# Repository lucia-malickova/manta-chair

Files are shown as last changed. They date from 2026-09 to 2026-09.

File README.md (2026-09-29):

# MANTA — the "one ribbon" chair (Open Chair)

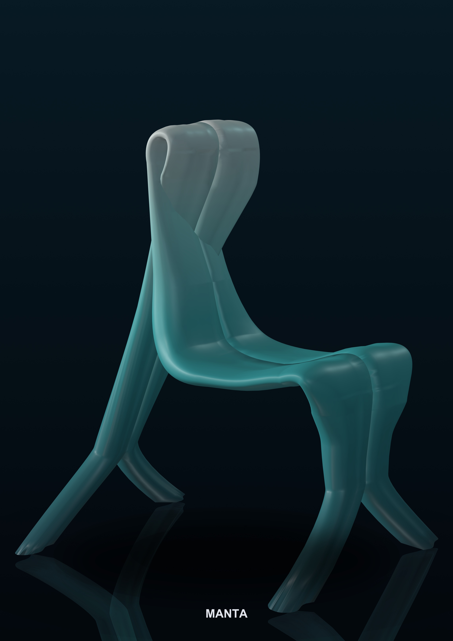
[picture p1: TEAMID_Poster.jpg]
MANTA poster


The whole chair is **one continuous ribbon**, **sliced crosswise** (like a
baguette) so every part fits a home printer and every joint stays strong.
Named for the manta ray — the forked feet read as fins, the tail-brace as a
fluke — and for the ocean's role as the planet's largest source of oxygen,
which the surface relief carries in its own graded texture, bold at the
floor and calming toward the crown.

No two of its 41 printed segments are identical, on purpose: nothing in
nature repeats, so nothing here does either. Change a few tables in
`manta_ribbon.py` and the same script regenerates a lighter, cheaper, or
differently-sized chair with the same joints — this repo *is* that script.

📄 [Full description (PDF)](TEAMID_Description.pdf) · 🖼 [Board](TEAMID_Board.jpg) · 🖼 [Poster](TEAMID_Poster.jpg)

Shared under **CC BY-NC-SA** — free to study, adapt, and reprint; not for
commercial resale.

---

## Requirements (Python packages)

```
pip install cadquery numpy scipy shapely trimesh matplotlib vtk pypdfium2 reportlab pillow
```

The first 3 are enough for the geometry itself. The rest are for the
renders / board / poster / PDF.

---

## Is everything OK? — one command

```
python manta_verify.py            # both variants, every check (~45 min)
python manta_verify.py --fast     # skips virtual assembly + PrusaSlicer (~5 min)
python manta_verify.py light      # one variant
```

It prints PASS/FAIL for strength, the print files (42 parts, all inside the
Prusa CORE One volume), peg clearance in the STLs, the virtual assembly, the
support PrusaSlicer really adds (< 2 %, < 0.5 g inside holes), and the
description/package limits — and ends with `ALL CHECKS PASSED` or the list
of what failed.

## Run order

| # | command | what it does | output |
|---|---|---|---|
| 1 | `python manta_ribbon.py` | **generator** — builds the ribbon, **slices it**, adds tenons + pins, exports the parts and the assembled chair | `MANTA_RIBBON/` |
| 1b | `python manta_print_ready.py manta_ribbon MANTA_RIBBON _print_ready_competition` | **print files**: generator -> least-support orientation that fits the bed (`manta_orient.py`, writes `ORIENT.json`) -> generator again, pin holes turned into teardrops pointing up for exactly those orientations -> same orientations applied | numbered, pre-rotated STLs |
| 1c | `python manta_slicer_check.py <folder>` | slices every part in **PrusaSlicer** (your own profile) and reports the support it really generates, and whether any of it is inside a hole | `SLICER_REPORT.txt` |
| 2 | `python manta_apply_template.py` | embeds the chair + numbered parts into the **official, unmodified** `3D_Template.stl` (chair centred in its 800x800mm footprint box, each part in its numbered 220x220x250mm cell) | overwrites `MANTA_RIBBON/MANTA_Chair.stl` + `MANTA_Assembly.stl` |
| 3 | `python manta_strength_check.py` | **strength + stability check** (first-order, pure math, live from the tables — also run automatically by step 1) | printed to the console |
| 4 | `python manta_ergonomics_check.py` | **ergonomics check** — 8 seat/backrest dimensions vs seating reference ranges | printed to the console |
| 5 | `python manta_uniqueness_check.py` | **uniqueness check** — proves no two segments share volume/area/bbox | printed to the console |
| 6 | `python manta_joint_test.py` | **physical joint test** — small pieces to print and glue | `MANTA_TEST/` |
| — | *renders and submission files:* | | |
| 7 | `python manta_render.py` | renders (poster + board views) | `_deliver/` |
| 8 | `python manta_explode.py` | exploded view + parts grid | `_deliver/` |
| 9 | `python manta_pdf.py` | description -> PDF | `TEAMID_Description.pdf` |
| 10 | `python manta_poster.py` | A2 poster | `TEAMID_Poster.jpg` |
| 11 | `python manta_board.py` | A2 board (on the official template) | `TEAMID_Board.jpg` |
| 12 | `python manta_package.py` | packs the submission files + checks total size | `ODOVZDANIE/` |

**Part numbering**: the official `3D_Template.stl` numbers its 49 cells
column-major (1,8,15,22,29,36,43 down column 1; 2,9,16,... down column 2;
etc) — that's fixed, unmodifiable template geometry. The Board's own key
graphic lays its numbers out row-major instead. Both are correct: only the
*number* has to match between the two (part "5" on the Board = part "5" in
the STL's cell "5"), not the box's on-page position.

**Slicing is NOT a separate file** — it lives inside `manta_ribbon.py`, in the
`build()` function: it makes crosswise cuts (by length + curvature, avoiding
the knee and lumbar), a lengthwise L/R cut on wide segments, conical tenons
at every cut, and a solid dia 11 pin only at the lumbar joints.

---

## Printing the parts

`TEAMID_Assembly.stl` is the **competition submission** format: all 42 parts
placed inside the official `3D_Template.stl` grid, because the brief
requires that. That template geometry is a non-solid reference grid (lines +
text, not a printable object) — a slicer will still try to load it alongside
your parts, which is confusing and pointless for an actual print.

For printing at home, use [`MANTA_RIBBON/`](MANTA_RIBBON) instead: the same
42 parts, no template geometry mixed in. Each file is named
`NN_SEG_xxx.stl`, where `NN` is the part number from the Board's key and the
exploded-view diagram (`01_SEG_00L.stl` = part 1, `42_PIN.stl` = part 42,
and so on) — so the file list itself tells you what to print against the
Board, no cross-referencing needed. `PARTS_LIST.txt` in that folder has the
same numbering.

**Every file in `MANTA_RIBBON/` and `MANTA_LIGHT/` is pre-rotated to the
orientation that needs the least support** — import and print as-is.

Honest numbers, **measured in PrusaSlicer** (`manta_slicer_check.py`
slices every file and reads the G-code back): a curved, fluted ribbon
segment can't always be printed with zero support, but it is **almost
support-free — under 1 % of the filament is support** (competition: 114 g
of 16.8 kg; `MANTA_LIGHT`: 83 g of 9.0 kg), all of it from the build plate,
most parts only a few grams. `manta_orient.py` tries ~400 orientations per
part and keeps the one that fits the Prusa CORE One's 250 x 220 x 270 mm
volume, stands on a solid base (>= 400 mm² footprint) and needs the least
support, with support inside a hole weighted 100x.

**Nothing grows inside the holes**, because each hole is shaped for the
way its part lies (`manta_teardrop.py`): a socket lying sideways gets a
teardrop roof pointing up, a socket end facing up is pointed (every
surface >= 60°), and the pin holes have no blind end at all — past the
pin's stop they narrow into a channel that runs out through the centre
seam. The one exception PrusaSlicer still shows is a ~0.3 g thin branch up
the pin channel of part 14; the channel is open at both ends, push it out
with a rod. `PARTS_LIST.txt` and `SLICER_REPORT.txt` in each folder list
the support per part.

In the slicer use **"Support on build plate only"** with an overhang
threshold of 45° or lower, never "Everywhere". (Earlier versions of these
docs claimed "no supports", then "29 of 42 parts need none"; neither was
checked in a real slicer, and the 45° socket points of that version still
got support inside them at a 45° threshold.)

---

## How to tune it

Everything is set in the `PARAMETERS` block at the top of `manta_ribbon.py`:
- `SPINE` — the ribbon's side profile (X = forward, Z = up)
- `W_S` — width along the length · `TH_S` — thickness along the length (follows the bending moment)
- `TWIST_S` — spiral twist of the section
- `SEG_MAX`, `FORK_SPLAY`, `TEN_R`, `PIN_R` ... — slicing and joints

`TEN_CLR = 0.12` mm was confirmed on a printed test joint (the cone slides
in with a little play; with the pin and no glue it already held hard).
Printers differ: print `MANTA_TEST/` (~2 h) first on yours, and if the
cone is too tight or too loose change `TEN_CLR` by 0.03 and regenerate.
The print STLs are exported at 0.03 mm tolerance so that this clearance
survives the export (`python manta_stl_fit_check.py` measures it).

**Every run of `manta_ribbon.py` re-checks itself.** Before exporting
anything, it calls `manta_strength_check.py`'s `worst_margin()`, which
re-derives the seat/lumbar/cut/leg section properties live from whatever
`W_S`/`TH_S` are currently set to (not a hand-copied snapshot) and runs the
same load case as the printed report. If tuning the tables has pushed the
weakest joint below the intended safety factor, generation stops with an
error instead of quietly writing an unsafe STL. Run
`python manta_strength_check.py` on its own any time for the full
13-check breakdown.

**A ready-made lighter variant — [`MANTA_LIGHT/`](MANTA_LIGHT).** Not
everyone needs a chair rated for a 120 kg dynamic sitter. `manta_ribbon_personal.py`
is the exact same generator with `TH_S` thinned to 75%, printed with 15%
gyroid and 4 perimeters; `manta_strength_check_personal.py` re-verifies it
for a **70 kg** sitter (x 1.8 dynamic x 2.0 safety): weakest glued check
**1.6x**, glued full-section joint **26x**. The PETG-only backup (peg + pin,
no epoxy) is **0.5x**, so this variant relies on the epoxy actually being
applied. With 15% infill the glue faces are only as good as their solid
skin: use at least 6 top / 5 bottom solid layers and only scuff them with
P120, don't sand through. Pins still at 100% infill. `MANTA_LIGHT/` is the
already-generated, numbered result: same 42 parts, same joints, about half
the filament (**9.0 kg vs 16.8 kg** in PrusaSlicer, ~160 h vs ~470 h; `manta_material_personal.py` for the
cost at your own filament price). Load-test it before sitting on it
(30 -> 50 -> 70 kg, each overnight). A demonstration variant, not the
competition entry — the competition files are untouched.

Want to print it in more than one colour? `python manta_colour_guide.py`
buckets the 41 segments into 4 filament colours by height (floor -> crown),
matching the same gradient the renders already use — prints exactly which
part numbers go in which colour and how many kg/EUR of each. Multi-colour
costs nothing extra: it's the same total filament, just split across spools.

---

## How the joint holds (so you don't have to worry)

The joint is **not "just a pin."** In order of importance:

1. **The full solid cross-section, glued face-to-face.** Every cut is
   perpendicular to the ribbon's axis, so you're gluing two flat faces of
   solid material against each other — 6,600–17,000 mm² of epoxy per joint.
   This is the main strength. (Margin in the strength check: **~26x**; the
   epoxy on the peg **3.5x**, counting only 80 % of its side because a
   sideways socket has a teardrop roof; weakest glued check **2.1x** — see
   `manta_strength_check.py`.)
2. **A conical peg (dia 27 at the face, 22 mm long)** at the centre of the
   cut — self-centring, it aligns the joint and carries shear. Only 3 mm of
   it is fused into its own part; the rest sits in the neighbour's socket
   (0.6 mm deeper than the peg, so the glue faces meet, not the tip; the
   socket's pointed end stays empty and takes the surplus glue and air).
3. **Dia 11 x 133 mm pins, printed SOLID (100% infill) and lying on
   their 2.2 mm flat** (so the layers run along the pin) — ONLY at the 2
   joints beside the lumbar, two per joint. One straight line per joint runs
   through both halves' pegs; from each side face a hole runs in along it,
   narrows in a long taper (the pin's stop) and continues as a dia 7 channel
   out through the centre seam — no blind end, so nothing inside it needs
   support. Slide each pin in until it stops. No pin sticks out; in three
   holes it ends 1 mm below the surface, in one ~27 mm below (the peg there
   sits deeper) — fill that mouth with epoxy. A cone in a cone slides straight out, so without glue
   the pin is the only thing holding it: the backup is peg root -> peg ->
   pin in *series*, and its capacity is the weakest of those. With the pin
   placed close to the face it comes to **0.9x** of the full design load
   (governed by the peg tearing out behind the pin) — a real limp-home
   backup, not a second main joint. An earlier version of the check *added*
   the peg and pin strengths together and reported 1.6x; that was wrong.

`python manta_joint_check.py` rebuilds every part and virtually assembles
the chair: every peg must land in its neighbour's socket, no peg end may
stick out of its own part, every socket must be closed inside ONE part
with at least 2 mm of wall around it, pins may only sit in holes, and no
two neighbouring parts may overlap. Where a whole piece meets a split L/R
pair (and vice versa) the whole piece carries two pegs, one per half, so no
socket is split across the seam. Every joint gets a peg in both variants;
where the part is thin the generator shortens the peg rather than leave less
than 2 mm of wall (it lists those in its report).

**Assembly order matters:** glue each L+R pair of a segment together
FIRST (their seam peg runs sideways, along that segment's own twisted
width direction), and only then join the segments crosswise (all crosswise
pegs of a joint are parallel, so a finished segment slides straight on).
The other way round cannot be assembled. Each part's number is engraved on
one of its glue faces (hidden once glued).

Epoxy on PETG: **sand the face (P120) and degrease** before gluing — otherwise
the epoxy won't bond well. Leave it clamped to cure for 24 h.

---

## Code files

- `manta_ribbon.py` — generator + slicing + joints + export
- `manta_apply_template.py` — embeds the chair/parts into the official `3D_Template.stl`
- `manta_strength_check.py` — strength + stability
- `manta_ergonomics_check.py` — seat/backrest dimensions vs standard reference ranges
- `manta_stl_fit_check.py` — measures the peg/socket clearance left in the exported print STLs
- `manta_joint_check.py` — virtual assembly: every peg seats in its neighbour, nothing sticks out or overlaps
- `manta_uniqueness_check.py` — proves no two of the 41 segments are geometrically identical
- `manta_orient.py` — rotates each part to the orientation needing the least support that fits the bed (solid base kept); writes `ORIENT.json`
- `manta_teardrop.py` — shapes sockets and pin holes for that orientation (teardrop roofs, pointed ends, pin channels) so nothing inside them needs support
- `manta_print_ready.py` — runs generator -> orient -> generator -> orient in the right order for one variant
- `manta_slicer_check.py` — slices every part in PrusaSlicer and reports the support it really adds (and any inside a hole), filament and print time
- `manta_print_list.py` — writes the numbered `PARTS_LIST.txt` with the slicer's per-part support
- `manta_joint_test.py` — physical joint test
- `manta_material.py` — filament use + cost from the real STL parts
- the remaining `manta_*.py` files = rendering / submission packaging
- `MANTA_Description_DRAFT.md` — the description text (edit, then run `manta_pdf.py`)
- `_board_base.png` — the rasterised official board template (without instructions)
- `3D_Template.stl` — the official 3D print file template (unmodified, as provided)
- `MANTA_RIBBON/` — the 42 individual part STLs, clean and ready to print (no template geometry) — see "Printing the parts" above

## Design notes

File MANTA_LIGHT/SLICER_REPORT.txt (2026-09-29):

# PrusaSlicer, profile: 0.28mm DRAFT @COREONE HF0.4 - Copy / Prusa CORE One HF0.4 nozzle / Prusament PETG @COREONE HF0.4 + top_solid_layers = 6
# part	support moves	of them inside a hole	support grams	part grams	support grams in holes	hours
01_SEG_00L.stl	37476	0	6.4	201	0.00	4.64
02_SEG_00R.stl	19457	0	4.3	195	0.00	3.96
03_SEG_01L.stl	11597	17	1.8	147	0.00	2.88
04_SEG_01R.stl	13867	0	2.4	152	0.00	3.13
05_SEG_02L.stl	1915	0	0.3	250	0.00	3.91
06_SEG_02R.stl	28396	17	4.9	276	0.00	5.38
07_SEG_03L.stl	67173	0	9.0	392	0.00	8.97
08_SEG_03R.stl	79090	0	10.7	447	0.00	10.23
09_SEG_04L.stl	1786	0	0.3	344	0.00	5.23
10_SEG_04R.stl	0	0	0.0	351	0.00	5.19
11_SEG_05L.stl	3401	0	0.6	350	0.00	5.50
12_SEG_05R.stl	13030	111	2.7	362	0.02	5.99
13_SEG_06L.stl	46219	0	7.1	488	0.00	8.86
14_SEG_06R.stl	15668	1044	4.4	468	0.30	7.83
15_SEG_07L.stl	1829	0	0.3	368	0.00	5.56
16_SEG_07R.stl	0	0	0.0	370	0.00	5.53
17_SEG_08L.stl	1809	0	0.3	198	0.00	3.09
18_SEG_08R.stl	23551	41	3.6	225	0.01	4.28
19_SEG_09L.stl	4226	0	0.7	163	0.00	2.84
20_SEG_09R.stl	2087	0	0.3	176	0.00	2.85
21_SEG_10L.stl	5947	0	0.8	154	0.00	2.59
22_SEG_10R.stl	6893	0	1.7	173	0.00	2.86
23_SEG_11L.stl	22135	0	3.6	125	0.00	2.97
24_SEG_11R.stl	5008	0	1.6	141	0.00	2.33
25_SEG_12L.stl	4236	0	0.5	129	0.00	2.21
26_SEG_12R.stl	4670	0	1.1	147	0.00	2.42
27_SEG_13L.stl	1301	0	0.2	96	0.00	1.59
28_SEG_13R.stl	3455	0	0.8	104	0.00	1.80
29_SEG_14.stl	0	0	0.0	160	0.00	2.54
30_SEG_15.stl	0	0	0.0	167	0.00	2.59
31_SEG_16.stl	0	0	0.0	172	0.00	2.69
32_SEG_17.stl	0	0	0.0	182	0.00	2.84
33_SEG_18.stl	0	0	0.0	200	0.00	3.06
34_SEG_19L.stl	964	0	0.2	120	0.00	2.05
35_SEG_19R.stl	853	0	0.2	120	0.00	2.02
36_SEG_20L.stl	6661	0	0.7	102	0.00	2.15
37_SEG_20R.stl	5599	0	0.6	98	0.00	1.94
38_SEG_21L.stl	15134	0	2.1	119	0.00	2.83
39_SEG_21R.stl	14121	0	2.2	121	0.00	2.71
40_SEG_22L.stl	20738	0	2.9	134	0.00	3.19
41_SEG_22R.stl	24152	0	3.8	142	0.00	3.38
42_PIN.stl	126	0	0.0	10	0.00	0.17

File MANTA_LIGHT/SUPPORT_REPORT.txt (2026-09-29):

01_SEG_00L.stl	73.2	93
02_SEG_00R.stl	52.1	988
03_SEG_01L.stl	27.1	1593
04_SEG_01R.stl	36.1	3996
05_SEG_02L.stl	2.5	3436
06_SEG_02R.stl	59.2	696
07_SEG_03L.stl	102.1	6693
08_SEG_03R.stl	116.5	6506
09_SEG_04L.stl	2.4	6485
10_SEG_04R.stl	0.0	6208
11_SEG_05L.stl	3.2	6023
12_SEG_05R.stl	19.4	444
13_SEG_06L.stl	97.4	9946
14_SEG_06R.stl	42.1	494
15_SEG_07L.stl	2.5	10489
16_SEG_07R.stl	0.0	10305
17_SEG_08L.stl	2.5	6993
18_SEG_08R.stl	40.7	847
19_SEG_09L.stl	3.6	4570
20_SEG_09R.stl	2.1	4403
21_SEG_10L.stl	8.8	4013
22_SEG_10R.stl	9.8	420
23_SEG_11L.stl	46.9	845
24_SEG_11R.stl	7.5	503
25_SEG_12L.stl	7.2	3225
26_SEG_12R.stl	6.6	413
27_SEG_13L.stl	1.2	2480
28_SEG_13R.stl	4.8	448
29_SEG_14.stl	0.0	4384
30_SEG_15.stl	0.0	4706
31_SEG_16.stl	0.0	5039
32_SEG_17.stl	0.0	5342
33_SEG_18.stl	0.0	5815
34_SEG_19L.stl	0.4	3047
35_SEG_19R.stl	0.3	2946
36_SEG_20L.stl	18.2	3438
37_SEG_20R.stl	12.1	3324
38_SEG_21L.stl	38.1	4052
39_SEG_21R.stl	34.8	3917
40_SEG_22L.stl	50.9	4784
41_SEG_22R.stl	54.5	5445
42_PIN.stl	0.0	1338

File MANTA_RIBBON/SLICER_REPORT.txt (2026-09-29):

# PrusaSlicer, profile: 0.28mm DRAFT @COREONE HF0.4 - Copy / Prusa CORE One HF0.4 nozzle / Prusament PETG @COREONE HF0.4 + layer_height = 0.2;perimeters = 5;fill_density = 35%
# part	support moves	of them inside a hole	support grams	part grams	support grams in holes	hours
01_SEG_00L.stl	49347	0	8.3	306	0.00	9.71
02_SEG_00R.stl	24131	0	5.2	314	0.00	9.19
03_SEG_01L.stl	22411	6	3.2	258	0.00	7.70
04_SEG_01R.stl	23312	0	3.3	262	0.00	7.76
05_SEG_02L.stl	2546	0	0.4	502	0.00	13.35
06_SEG_02R.stl	63446	41	11.9	512	0.01	15.99
07_SEG_03L.stl	135787	0	19.7	783	0.00	26.32
08_SEG_03R.stl	86796	0	10.2	820	0.00	25.63
09_SEG_04L.stl	2581	0	0.3	695	0.00	18.32
10_SEG_04R.stl	0	0	0.0	710	0.00	18.62
11_SEG_05L.stl	5005	0	0.8	711	0.00	19.35
12_SEG_05R.stl	0	0	0.0	717	0.00	18.83
13_SEG_06L.stl	66952	0	9.4	976	0.00	28.02
14_SEG_06R.stl	32755	1089	7.3	978	0.24	27.54
15_SEG_07L.stl	2432	0	0.3	748	0.00	19.88
16_SEG_07R.stl	0	0	0.0	761	0.00	20.24
17_SEG_08L.stl	2212	0	0.3	395	0.00	10.46
18_SEG_08R.stl	0	0	0.0	398	0.00	10.53
19_SEG_09L.stl	5614	0	0.8	301	0.00	8.12
20_SEG_09R.stl	2775	0	0.4	325	0.00	8.50
21_SEG_10L.stl	10134	0	1.2	276	0.00	7.38
22_SEG_10R.stl	29752	80	3.8	321	0.01	9.56
23_SEG_11L.stl	35549	21	4.0	197	0.00	6.45
24_SEG_11R.stl	7286	0	1.8	249	0.00	6.48
25_SEG_12L.stl	11885	0	1.2	212	0.00	5.79
26_SEG_12R.stl	7047	0	1.4	237	0.00	6.07
27_SEG_13L.stl	2123	0	0.2	166	0.00	4.46
28_SEG_13R.stl	5712	0	1.2	172	0.00	4.44
29_SEG_14.stl	0	0	0.0	287	0.00	7.41
30_SEG_15.stl	0	0	0.0	320	0.00	8.32
31_SEG_16.stl	0	0	0.0	334	0.00	8.78
32_SEG_17.stl	0	0	0.0	358	0.00	9.51
33_SEG_18.stl	0	0	0.0	395	0.00	10.49
34_SEG_19L.stl	1301	0	0.3	227	0.00	6.10
35_SEG_19R.stl	1189	0	0.3	231	0.00	6.24
36_SEG_20L.stl	3115	34	0.6	171	0.01	4.71
37_SEG_20R.stl	10795	0	1.1	170	0.00	4.94
38_SEG_21L.stl	25738	0	3.1	189	0.00	5.89
39_SEG_21R.stl	24309	0	3.2	197	0.00	6.11
40_SEG_22L.stl	32624	0	4.0	198	0.00	6.44
41_SEG_22R.stl	28536	17	4.4	214	0.00	6.66
42_PIN.stl	0	0	0.0	11	0.00	0.23

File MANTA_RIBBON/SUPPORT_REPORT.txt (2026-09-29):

01_SEG_00L.stl	82.2	763
02_SEG_00R.stl	44.7	1298
03_SEG_01L.stl	36.6	518
04_SEG_01R.stl	47.6	4687
05_SEG_02L.stl	2.5	4401
06_SEG_02R.stl	78.4	2125
07_SEG_03L.stl	215.2	484
08_SEG_03R.stl	104.6	8410
09_SEG_04L.stl	2.6	8618
10_SEG_04R.stl	0.0	8278
11_SEG_05L.stl	3.7	8219
12_SEG_05R.stl	0.0	7877
13_SEG_06L.stl	100.2	13224
14_SEG_06R.stl	67.4	765
15_SEG_07L.stl	2.5	13360
16_SEG_07R.stl	0.0	13180
17_SEG_08L.stl	2.5	8832
18_SEG_08R.stl	0.0	8692
19_SEG_09L.stl	3.6	5920
20_SEG_09R.stl	2.1	5747
21_SEG_10L.stl	9.5	5223
22_SEG_10R.stl	44.1	711
23_SEG_11L.stl	43.6	4896
24_SEG_11R.stl	10.0	591
25_SEG_12L.stl	14.1	4149
26_SEG_12R.stl	8.9	499
27_SEG_13L.stl	2.1	3143
28_SEG_13R.stl	9.5	504
29_SEG_14.stl	0.0	5382
30_SEG_15.stl	0.0	5875
31_SEG_16.stl	0.0	6348
32_SEG_17.stl	0.1	6749
33_SEG_18.stl	0.0	7369
34_SEG_19L.stl	0.7	3924
35_SEG_19R.stl	0.4	3798
36_SEG_20L.stl	3.3	457
37_SEG_20R.stl	17.2	4251
38_SEG_21L.stl	45.9	4913
39_SEG_21R.stl	41.2	4753
40_SEG_22L.stl	56.9	5443
41_SEG_22R.stl	48.9	1183
42_PIN.stl	0.0	1338

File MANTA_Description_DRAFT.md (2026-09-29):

# MANTA

**One continuous ribbon. One gesture. Cut like a baguette so it can be printed at home and still hold an adult.**

## Idea

MANTA is a single thick ribbon: floor, dished seat, cantilevered backrest,
forward-curled crown, tail-brace, back to the floor — no separate legs, no
frame, no visible assembly. The name is literal: forked feet read as fins,
the tail-brace as a fluke. The ocean makes most of the oxygen we breathe,
and the manta ray is one of its health indicators — so the surface carries
the story too: flutes that follow the ribbon's own motion, bold at the
floor and easing toward the crown, capped where you sit so they never press into a bone.

## Biomimicry as structure, not ornament

Each rule carries load:

- **Wolff's law** — thickness follows the bending moment: 84 mm at the lumbar
  knot, 50 mm at the knee, a 32 mm blade at the crown.
- **Murray's law** — the lumbar, the one true junction, is the cube-root-sum
  of seat, backrest and tail; every transition filleted.
- **Spiral fibre** — the flutes follow the stress path and stiffen by
  corrugation; the section twists up to 20° through the backrest.
- **Shell curvature** — the closed superelliptical section and dished seat
  carry load in membrane action.
- **Fiddlehead scroll** — the forward-curled crown closes the backrest into a
  tube, not an open cantilever.
- **Buttress roots** — each foot forks into two splayed prongs.

## Printing

41 segments (each ≤ 212 × 220 × 250 mm), auto-oriented for the least
support: **almost support-free**, under 1 % of the filament (PrusaSlicer),
none inside the holes — each is shaped for the way its part lies. PETG,
0.2 mm layers, 5 perimeters, 35 % gyroid, solid pins. ~17 kg, ~470 h on
one printer, ~90 €.

## Assembly — computed joints, no screws

Cuts and joints are computed, not drawn by hand. The script slices the
ribbon **crosswise** by length and curvature, keeping every cut ≥ 70 mm from
the knee and lumbar, where bending peaks. Every joint is a full solid cross-section (7,000–17,000 mm²),
epoxied, with a self-centring conical peg sized to the local thickness,
centred on its face, shrunk until its socket keeps a 2 mm wall.
Wide segments split along a flute-hidden keel. Only the two most-loaded
lumbar joints add a solid Ø11 pin. Every part's number is engraved on a glue face.
One command (manta_verify.py) re-checks it all: strength, a **virtual
assembly** (pegs seated, 2 mm walls, no overlaps), bed fit, real-slicer support.

## Stability and load

First-order check (120 kg × 1.8 dynamic × 2.0 safety): every member passes; glued full-section joint 26×,
weakest glued check 2.1×; with no glue at all, peg and pin still carry
0.9×. Tipping 0.56 sideways, 0.55–0.77 rearward; safe static load
~250 kg. Seat 429 × 364 mm, 428 mm high; 8/8 ergonomics checks pass.

## Open design — nothing repeats

Nothing in nature repeats, so no two parts here do either: all 41
segments are geometrically unique (script-verified). Change
the tables and the script regenerates a leaner chair with its joints and
checks; a 70 kg, half-filament variant is in the repo (link below).

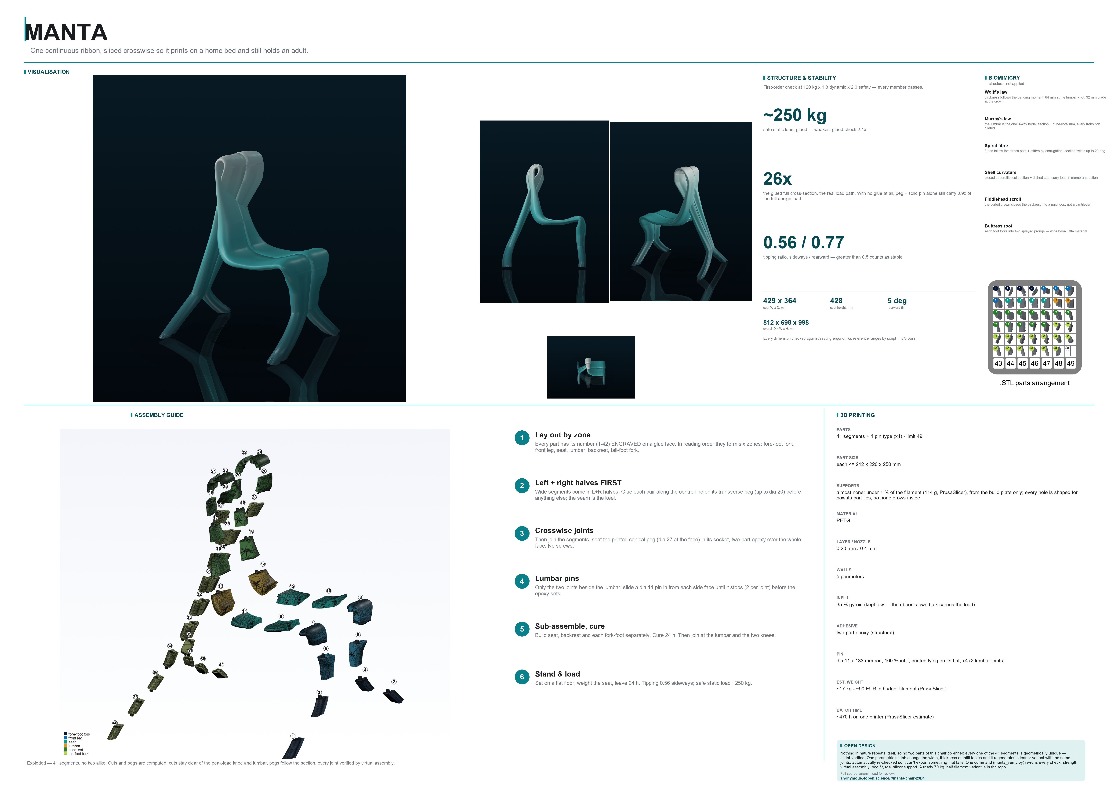
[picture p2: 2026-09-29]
TEAMID_Board.jpg

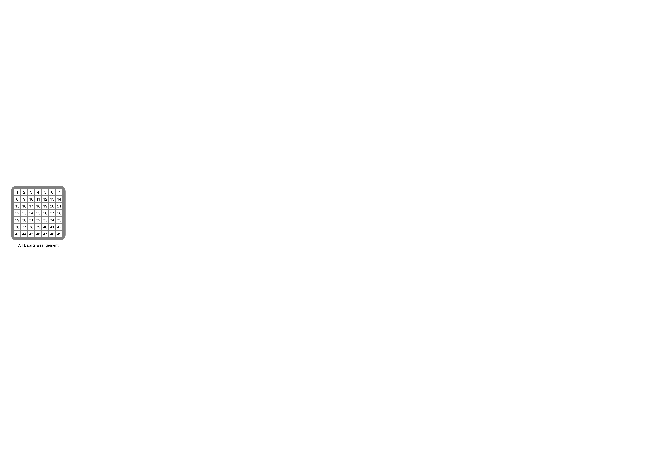
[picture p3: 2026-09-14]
_board_base.png

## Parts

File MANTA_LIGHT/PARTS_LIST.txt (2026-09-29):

MANTA — numbered, pre-oriented printable parts (matches Board key)

LIGHT variant — 70 kg design occupant, NOT the competition entry.
Print settings it was checked for (manta_strength_check_personal.py):
  4 perimeters, 15 % gyroid infill, >= 6 top / 5 bottom solid layers;
  PIN: 100 % infill (solid). Load-test before use: 30 -> 50 -> 70 kg.

Each file is pre-rotated to the orientation needing the LEAST support, on a solid
base (python manta_orient.py) — import and print as-is. Slicer: "Support on build
plate only" (never "Everywhere"), overhang threshold 45° or lower. Every hole is
shaped for the way its part lies: sockets that lie sideways have a teardrop roof,
ends that face up are pointed, pin holes run on through the seam as a narrow
channel -- so no support grows inside them (checked in PrusaSlicer).
Pins: 100 % infill, lying on their flat.
Every peg sits in a socket closed inside ONE neighbour part with >= 2 mm wall
(python manta_joint_check.py); >= 0.06 mm clearance survives in these STL files
(python manta_stl_fit_check.py). Each part number is ENGRAVED on a glue face.
ASSEMBLY: glue each L+R pair first, then join segments. Print both halves of a
segment from the SAME version of the files.

Support tags below = what PrusaSlicer, profile: 0.28mm DRAFT @COREONE HF0.4 - Copy / Prusa CORE One HF0.4 nozzle / Prusament PETG @COREONE HF0.4 + top_solid_layers = 6 actually generates.

BOARD LEGEND  (42 items, limit 49)
 1. SEG_00L      1x   SUPPORT from build plate (~6 g)
 2. SEG_00R      1x   SUPPORT from build plate (~4 g)
 3. SEG_01L      1x   SUPPORT from build plate (~2 g)
 4. SEG_01R      1x   SUPPORT from build plate (~2 g)
 5. SEG_02L      1x   a few specks of support from the build plate (< 1 g)
 6. SEG_02R      1x   SUPPORT from build plate (~5 g)
 7. SEG_03L      1x   SUPPORT from build plate (~9 g)
 8. SEG_03R      1x   SUPPORT from build plate (~11 g)
 9. SEG_04L      1x   a few specks of support from the build plate (< 1 g)
10. SEG_04R      1x   no support
11. SEG_05L      1x   SUPPORT from build plate (~1 g)
12. SEG_05R      1x   SUPPORT from build plate (~3 g)
13. SEG_06L      1x   SUPPORT from build plate (~7 g)
14. SEG_06R      1x   SUPPORT from build plate (~4 g)  -- ~0.3 g is a thin branch up a pin channel: it is open at both ends, push it out with a rod
15. SEG_07L      1x   a few specks of support from the build plate (< 1 g)
16. SEG_07R      1x   no support
17. SEG_08L      1x   a few specks of support from the build plate (< 1 g)
18. SEG_08R      1x   SUPPORT from build plate (~4 g)
19. SEG_09L      1x   SUPPORT from build plate (~1 g)
20. SEG_09R      1x   a few specks of support from the build plate (< 1 g)
21. SEG_10L      1x   SUPPORT from build plate (~1 g)
22. SEG_10R      1x   SUPPORT from build plate (~2 g)
23. SEG_11L      1x   SUPPORT from build plate (~4 g)
24. SEG_11R      1x   SUPPORT from build plate (~2 g)
25. SEG_12L      1x   SUPPORT from build plate (~0 g)
26. SEG_12R      1x   SUPPORT from build plate (~1 g)
27. SEG_13L      1x   a few specks of support from the build plate (< 1 g)
28. SEG_13R      1x   SUPPORT from build plate (~1 g)
29. SEG_14       1x   no support
30. SEG_15       1x   no support
31. SEG_16       1x   no support
32. SEG_17       1x   no support
33. SEG_18       1x   no support
34. SEG_19L      1x   a few specks of support from the build plate (< 1 g)
35. SEG_19R      1x   a few specks of support from the build plate (< 1 g)
36. SEG_20L      1x   SUPPORT from build plate (~1 g)
37. SEG_20R      1x   SUPPORT from build plate (~1 g)
38. SEG_21L      1x   SUPPORT from build plate (~2 g)
39. SEG_21R      1x   SUPPORT from build plate (~2 g)
40. SEG_22L      1x   SUPPORT from build plate (~3 g)
41. SEG_22R      1x   SUPPORT from build plate (~4 g)
42. PIN          4x   no support  -- print at 100 % infill (solid), lying on its flat

crosswise joint (baguette-cut): conical peg dia 27 at the face, 22 mm into the neighbour's socket, + two-part epoxy on the whole face
lengthwise joint (L/R seam): transverse peg up to dia 20 + epoxy
PIN dia 11: 4x, printed SOLID (100% infill) lying on its flat, 2 per lumbar joint, slid in from each side face until it stops

WHOLE CHAIR (PrusaSlicer, pins x4): 9.0 kg of filament, of which support 83 g (0.9 %), ~159 h of printing on one printer

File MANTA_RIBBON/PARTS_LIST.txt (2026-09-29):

MANTA — numbered, pre-oriented printable parts (matches Board key)

Each file is pre-rotated to the orientation needing the LEAST support, on a solid
base (python manta_orient.py) — import and print as-is. Slicer: "Support on build
plate only" (never "Everywhere"), overhang threshold 45° or lower. Every hole is
shaped for the way its part lies: sockets that lie sideways have a teardrop roof,
ends that face up are pointed, pin holes run on through the seam as a narrow
channel -- so no support grows inside them (checked in PrusaSlicer).
Pins: 100 % infill, lying on their flat.
Every peg sits in a socket closed inside ONE neighbour part with >= 2 mm wall
(python manta_joint_check.py); >= 0.06 mm clearance survives in these STL files
(python manta_stl_fit_check.py). Each part number is ENGRAVED on a glue face.
ASSEMBLY: glue each L+R pair first, then join segments. Print both halves of a
segment from the SAME version of the files.

Support tags below = what PrusaSlicer, profile: 0.28mm DRAFT @COREONE HF0.4 - Copy / Prusa CORE One HF0.4 nozzle / Prusament PETG @COREONE HF0.4 + layer_height = 0.2;perimeters = 5;fill_density = 35% actually generates.

BOARD LEGEND  (42 items, limit 49)
 1. SEG_00L      1x   SUPPORT from build plate (~8 g)
 2. SEG_00R      1x   SUPPORT from build plate (~5 g)
 3. SEG_01L      1x   SUPPORT from build plate (~3 g)
 4. SEG_01R      1x   SUPPORT from build plate (~3 g)
 5. SEG_02L      1x   a few specks of support from the build plate (< 1 g)
 6. SEG_02R      1x   SUPPORT from build plate (~12 g)
 7. SEG_03L      1x   SUPPORT from build plate (~20 g)
 8. SEG_03R      1x   SUPPORT from build plate (~10 g)
 9. SEG_04L      1x   a few specks of support from the build plate (< 1 g)
10. SEG_04R      1x   no support
11. SEG_05L      1x   SUPPORT from build plate (~1 g)
12. SEG_05R      1x   no support
13. SEG_06L      1x   SUPPORT from build plate (~9 g)
14. SEG_06R      1x   SUPPORT from build plate (~7 g)  -- ~0.2 g is a thin branch up a pin channel: it is open at both ends, push it out with a rod
15. SEG_07L      1x   a few specks of support from the build plate (< 1 g)
16. SEG_07R      1x   no support
17. SEG_08L      1x   a few specks of support from the build plate (< 1 g)
18. SEG_08R      1x   no support
19. SEG_09L      1x   SUPPORT from build plate (~1 g)
20. SEG_09R      1x   a few specks of support from the build plate (< 1 g)
21. SEG_10L      1x   SUPPORT from build plate (~1 g)
22. SEG_10R      1x   SUPPORT from build plate (~4 g)
23. SEG_11L      1x   SUPPORT from build plate (~4 g)
24. SEG_11R      1x   SUPPORT from build plate (~2 g)
25. SEG_12L      1x   SUPPORT from build plate (~1 g)
26. SEG_12R      1x   SUPPORT from build plate (~1 g)
27. SEG_13L      1x   a few specks of support from the build plate (< 1 g)
28. SEG_13R      1x   SUPPORT from build plate (~1 g)
29. SEG_14       1x   no support
30. SEG_15       1x   no support
31. SEG_16       1x   no support
32. SEG_17       1x   no support
33. SEG_18       1x   no support
34. SEG_19L      1x   a few specks of support from the build plate (< 1 g)
35. SEG_19R      1x   a few specks of support from the build plate (< 1 g)
36. SEG_20L      1x   SUPPORT from build plate (~1 g)
37. SEG_20R      1x   SUPPORT from build plate (~1 g)
38. SEG_21L      1x   SUPPORT from build plate (~3 g)
39. SEG_21R      1x   SUPPORT from build plate (~3 g)
40. SEG_22L      1x   SUPPORT from build plate (~4 g)
41. SEG_22R      1x   SUPPORT from build plate (~4 g)
42. PIN          4x   no support  -- print at 100 % infill (solid), lying on its flat

crosswise joint (baguette-cut): conical peg dia 27 at the face, 22 mm into the neighbour's socket, + two-part epoxy on the whole face
lengthwise joint (L/R seam): transverse peg up to dia 20 + epoxy
PIN dia 11: 4x, printed SOLID (100% infill) lying on its flat, 2 per lumbar joint, slid in from each side face until it stops

WHOLE CHAIR (PrusaSlicer, pins x4): 16.8 kg of filament, of which support 114 g (0.7 %), ~467 h of printing on one printer

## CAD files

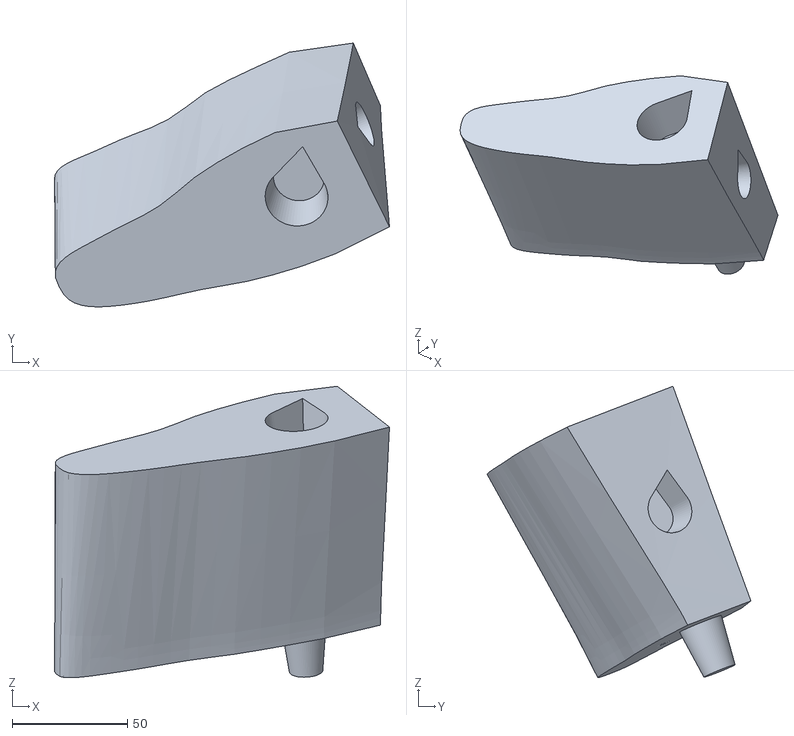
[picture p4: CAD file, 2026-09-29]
MANTA_LIGHT/18_SEG_08R.stl
145.3 x 114.4 x 126.4

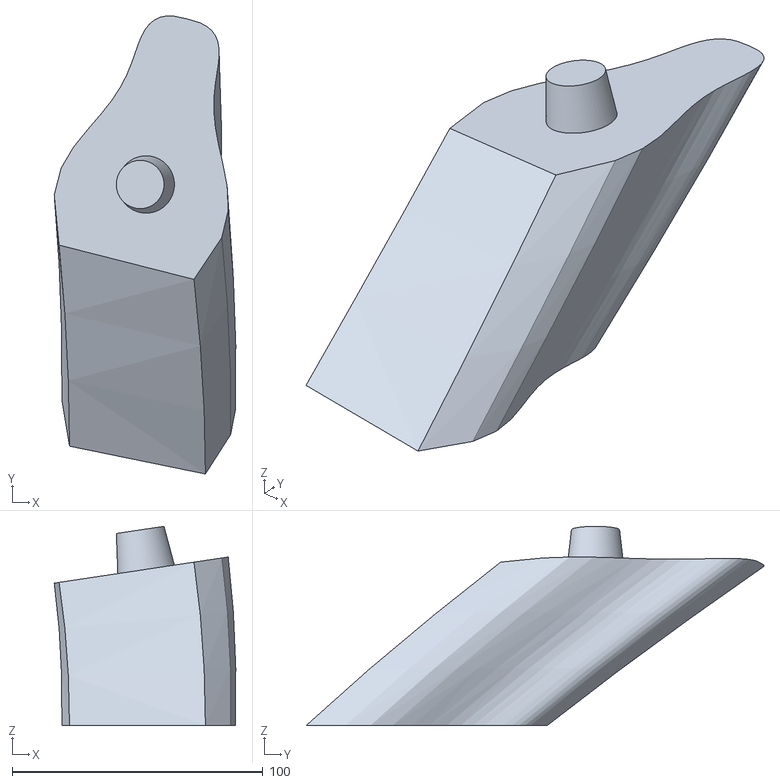
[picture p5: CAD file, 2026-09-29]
MANTA_RIBBON/39_SEG_21R.stl
72.4 x 182.6 x 79.5

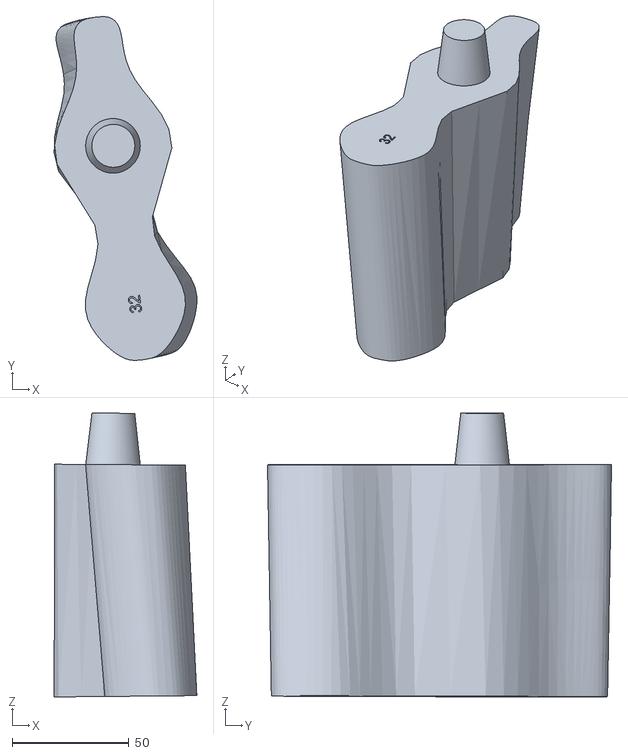
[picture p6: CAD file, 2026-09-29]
MANTA_LIGHT/32_SEG_17.stl
61.1 x 147.2 x 121.5

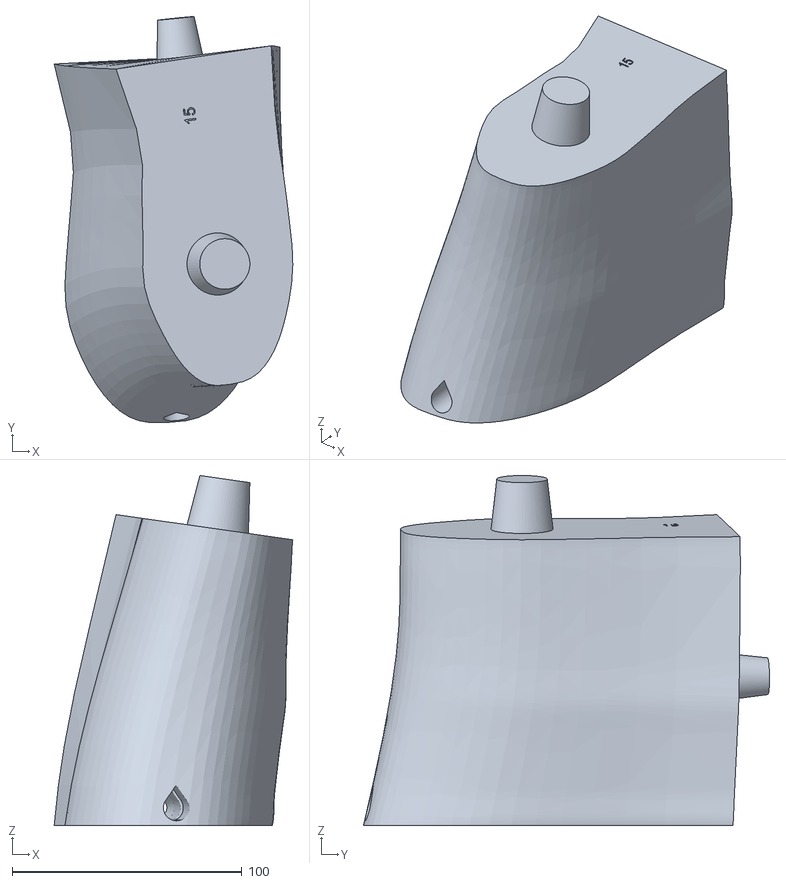
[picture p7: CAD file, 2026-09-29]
MANTA_RIBBON/15_SEG_07L.stl
103.9 x 176.8 x 152.4

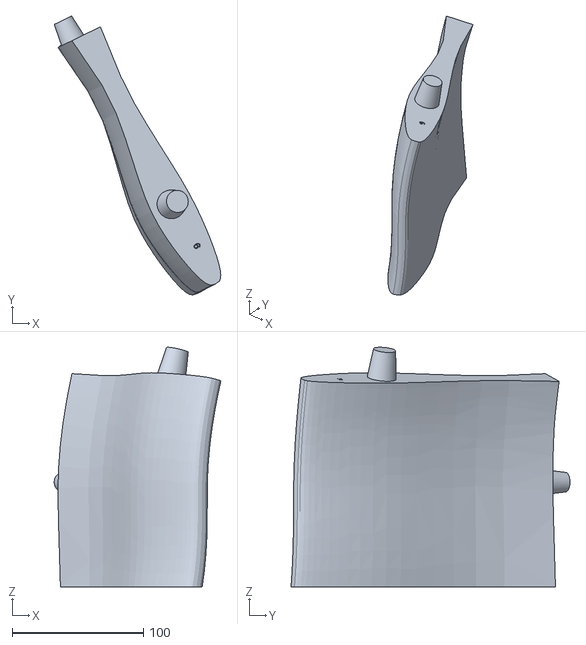
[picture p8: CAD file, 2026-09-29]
MANTA_LIGHT/09_SEG_04L.stl
126.9 x 212.4 x 182.5

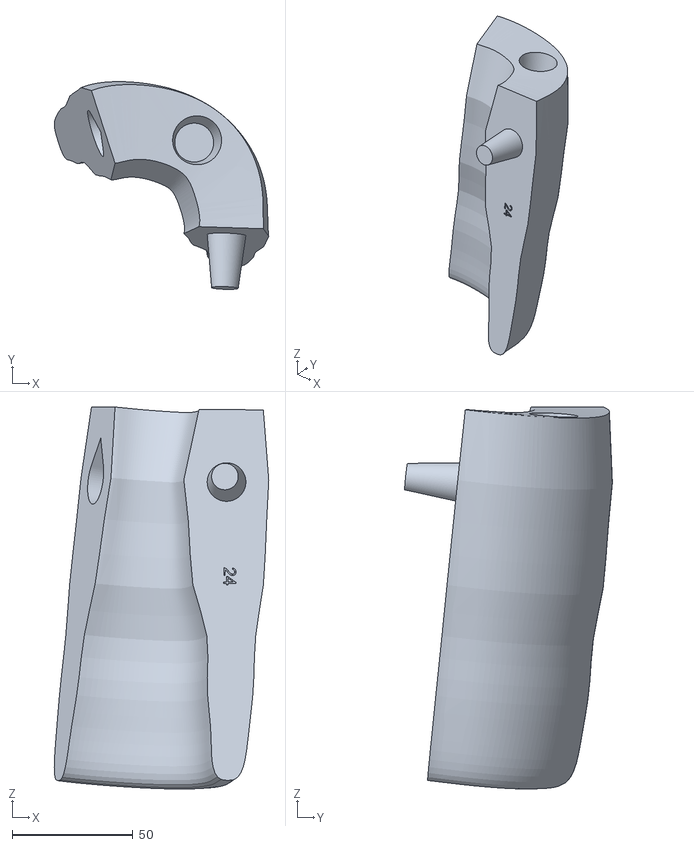
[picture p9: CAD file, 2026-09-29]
MANTA_RIBBON/24_SEG_11R.stl
88.7 x 86.0 x 158.0

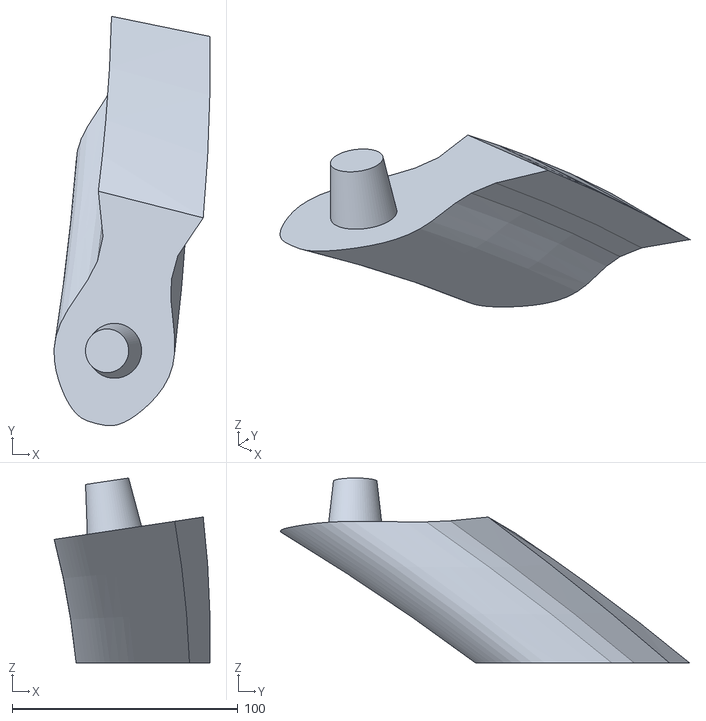
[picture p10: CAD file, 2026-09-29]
MANTA_LIGHT/38_SEG_21L.stl
69.0 x 181.3 x 81.9

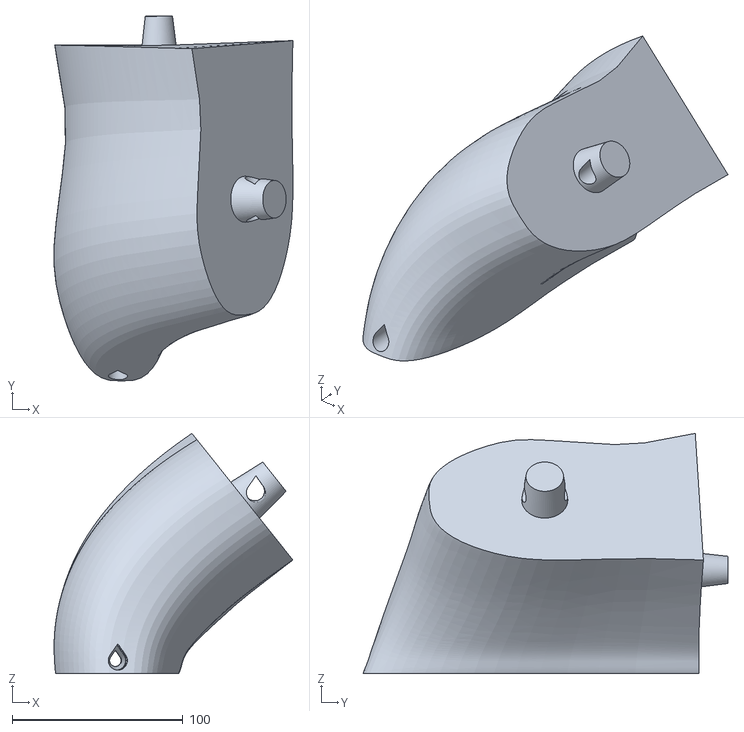
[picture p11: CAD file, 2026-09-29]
MANTA_RIBBON/13_SEG_06L.stl
140.1 x 214.0 x 140.8

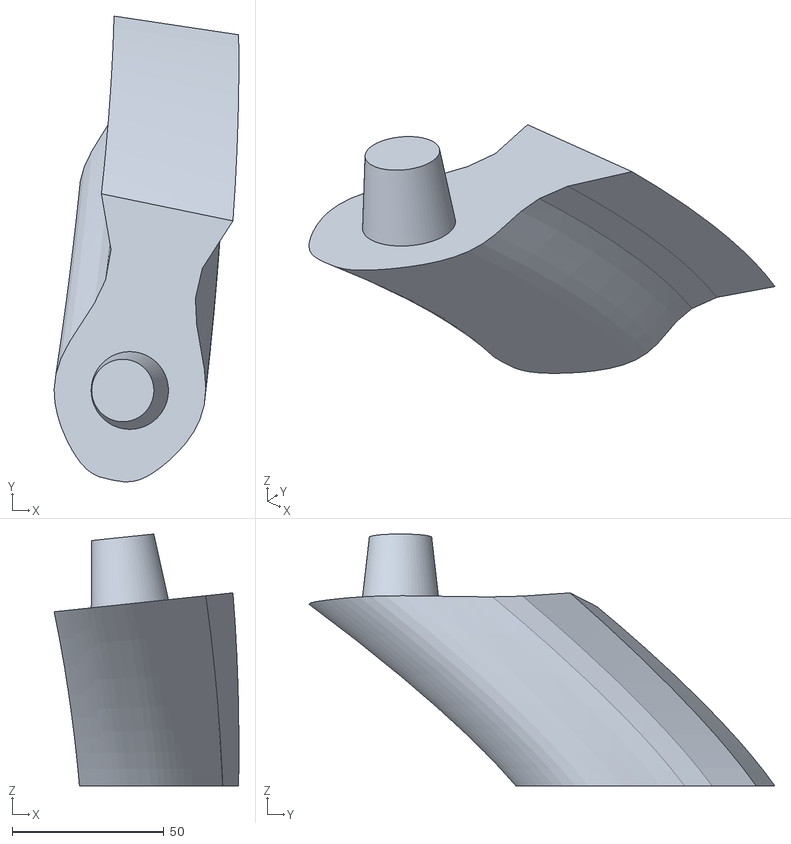
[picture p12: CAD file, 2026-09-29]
MANTA_LIGHT/36_SEG_20L.stl
60.8 x 153.3 x 82.9

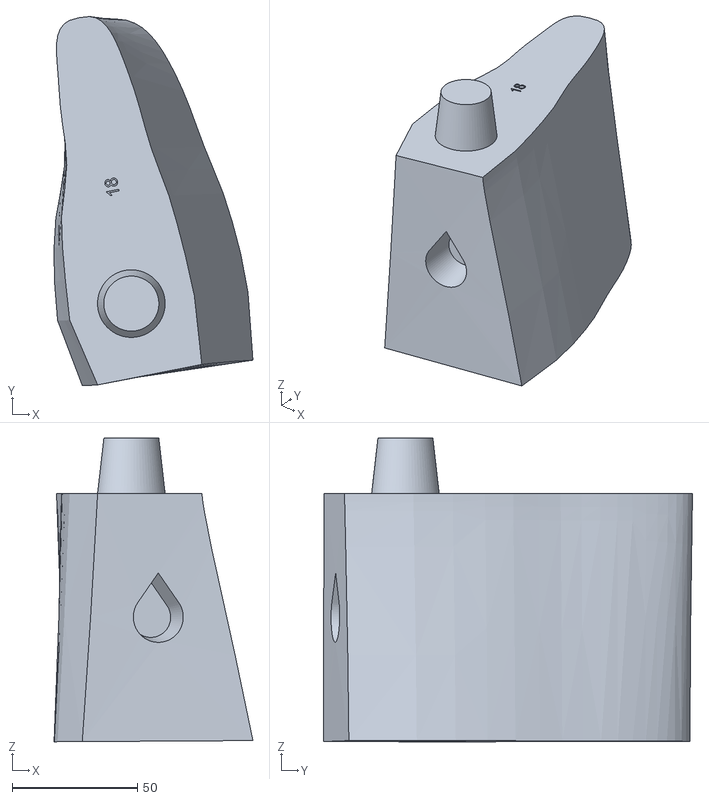
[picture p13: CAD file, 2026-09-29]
MANTA_RIBBON/18_SEG_08R.stl
79.5 x 147.5 x 121.3

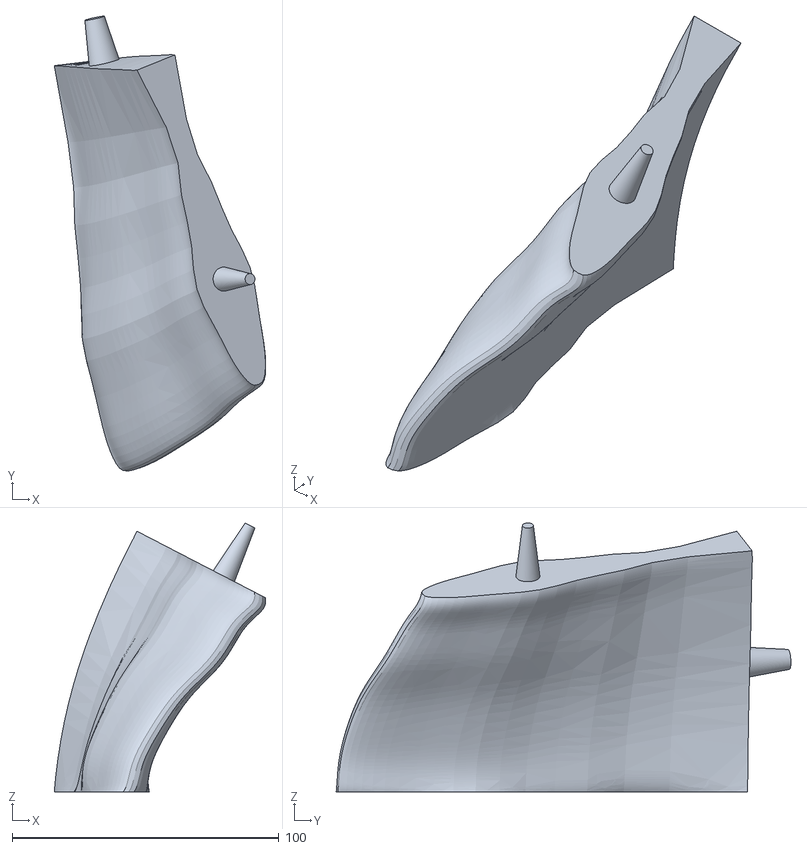
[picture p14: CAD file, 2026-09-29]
MANTA_LIGHT/25_SEG_12L.stl
79.3 x 170.6 x 100.9

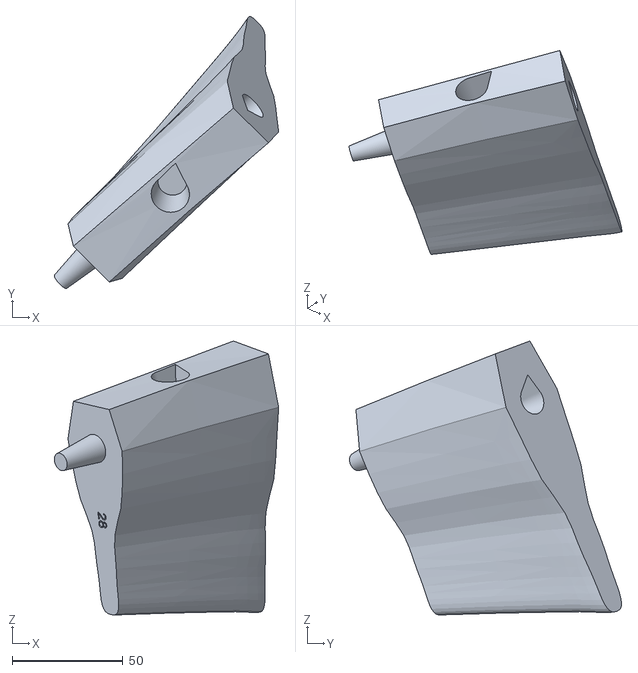
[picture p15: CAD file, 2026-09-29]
MANTA_RIBBON/28_SEG_13R.stl
101.4 x 123.0 x 123.9

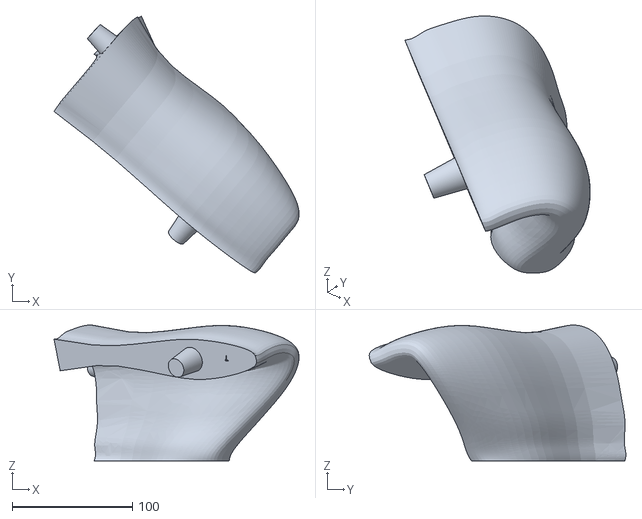
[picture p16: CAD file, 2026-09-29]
MANTA_LIGHT/07_SEG_03L.stl
203.5 x 213.3 x 112.8

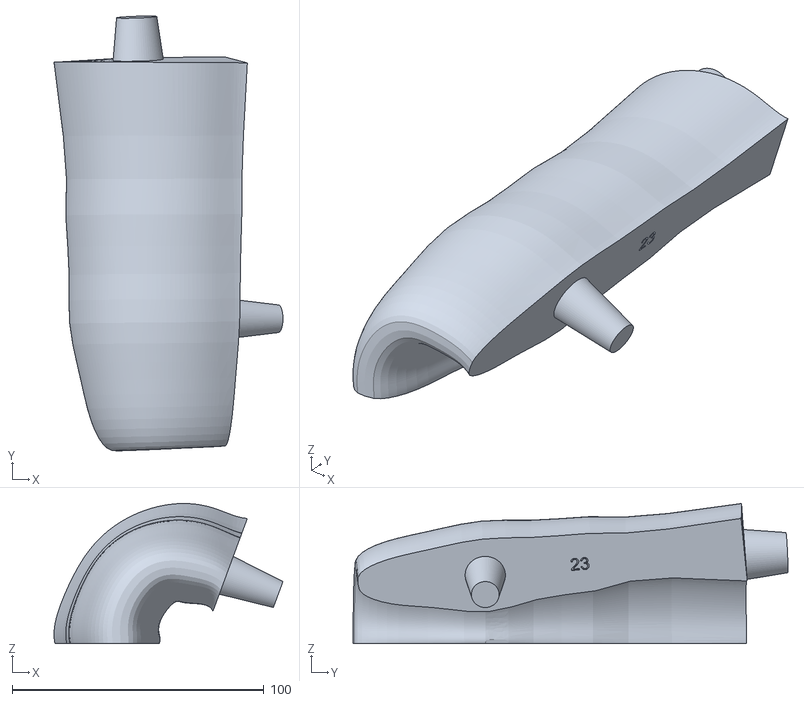
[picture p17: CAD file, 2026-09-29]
MANTA_RIBBON/23_SEG_11L.stl
91.0 x 172.9 x 55.7

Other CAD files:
MANTA_LIGHT/27_SEG_13L.stl
MANTA_RIBBON/41_SEG_22R.stl
MANTA_LIGHT/04_SEG_01R.stl
MANTA_RIBBON/26_SEG_12R.stl
MANTA_LIGHT/01_SEG_00L.stl
MANTA_LIGHT/02_SEG_00R.stl
MANTA_LIGHT/03_SEG_01L.stl
MANTA_LIGHT/05_SEG_02L.stl
MANTA_LIGHT/06_SEG_02R.stl
MANTA_LIGHT/08_SEG_03R.stl
MANTA_LIGHT/10_SEG_04R.stl
MANTA_LIGHT/11_SEG_05L.stl
MANTA_LIGHT/12_SEG_05R.stl
MANTA_LIGHT/13_SEG_06L.stl
MANTA_LIGHT/14_SEG_06R.stl
MANTA_LIGHT/15_SEG_07L.stl
MANTA_LIGHT/16_SEG_07R.stl
MANTA_LIGHT/17_SEG_08L.stl
MANTA_LIGHT/19_SEG_09L.stl
MANTA_LIGHT/20_SEG_09R.stl
MANTA_LIGHT/21_SEG_10L.stl
MANTA_LIGHT/22_SEG_10R.stl
MANTA_LIGHT/23_SEG_11L.stl
MANTA_LIGHT/24_SEG_11R.stl
MANTA_LIGHT/26_SEG_12R.stl
MANTA_LIGHT/28_SEG_13R.stl
MANTA_LIGHT/29_SEG_14.stl
MANTA_LIGHT/30_SEG_15.stl
MANTA_LIGHT/31_SEG_16.stl
MANTA_LIGHT/33_SEG_18.stl
MANTA_LIGHT/34_SEG_19L.stl
MANTA_LIGHT/35_SEG_19R.stl
MANTA_LIGHT/37_SEG_20R.stl
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

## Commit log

2026-09-22 Remove personal identifiers for competition anonymity; fix 41 vs 42 segment count; refresh Board and Description to current design
2026-09-22 Link the anonymised review repo from the Board and Description instead of a bare CC-BY-NC-SA mention
2026-09-23 Add individual part STLs (MANTA_RIBBON/) for clean home printing, separate from the competition's template-embedded Assembly.stl
    [PIN.stl, SEG_00L.stl, SEG_00R.stl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]
2026-09-23 Number the print-ready part files to match the Board key (NN_SEG_xxx.stl), so the file list itself says what to print
    [01_SEG_00L.stl, 02_SEG_00R.stl, 03_SEG_01L.stl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]
2026-09-23 Wire strength check to the live tables and add an automatic export gate
    - manta_strength_check.py now reads seat/lumbar/cut/leg section
    properties directly from manta_ribbon.py's W_S/TH_S tables and the
    real cut_stations(), instead of a hand-copied snapshot that had
    drifted out of sync (LUMBAR_W was off by 25%).
    - Removed a phantom 'front leg pin' check — no pin is actually placed
    there by build(); pins only exist at the 2 cuts beside the lumbar.
    - manta_ribbon.py now calls worst_margin() before exporting anything
    and refuses to write STL files if the weakest joint has dropped
    below the intended safety factor, so a leaner/thinner retune can't
    silently produce an unsafe chair.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
2026-09-23 Fix seat depth and overall bounding-box figures — the claimed 430x430mm seat was stale; the real depth (364mm, measured live) is the number the ergonomics check actually flagged
2026-09-23 Fix seat-depth ergonomics range to a general/dining-chair reference (was task-chair range) and state the honest, now-passing ergonomics check on the Board and Description
2026-09-23 Add manta_uniqueness_check.py — proves no two segments share volume/area/bounding-box, instead of just claiming it
2026-09-23 Colour-code the six assembly zones (fore-foot fork/front leg/seat/lumbar/backrest/tail-foot fork) consistently in the exploded view and the key grid, so the assembly logic reads before anyone starts 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
2026-09-23 Fill the Board's empty columns — bigger stats, added dimension strip, enlarged assembly steps; fixed a layout collision where the new content overlapped the key grid
2026-09-23 Ground the renders (floor plane, contact shadow, faint reflection) and rebalance lighting so the two grazing highlights stop reading as two separate ribbons
2026-09-23 Remove the opaque floor plane that was blocking the reflection from every angle except pure side-on; shadow discs alone now ground the object at every camera angle
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2026-09-23 Add MANTA_LIGHT/ — a ready-made 90kg-rated, ~40% lighter personal variant (thinned TH_S, verified by its own strength-check copy), and mention it on the Board and Description
    [01_SEG_00L.stl, 02_SEG_00R.stl, 03_SEG_01L.stl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]
2026-09-23 Add manta_colour_guide.py (saves the multi-colour breakdown as a real, reproducible script instead of chat text) and fix the personal variant's filament price to the real 6.39 EUR/kg
2026-09-23 Pre-orient every printable part for zero supports — measured, not assumed
    The old per-part 'print STANDING' note came from an unverified turn-angle
    heuristic. Checked directly on the exported meshes: as-designed orientation
    left an average 18% of each part's surface overhanging past 45 degrees
    (worst part 38%) -- the slicer asking for supports was correct, the note
    was wrong. manta_orient.py searches ~100 build directions per part and
    picks the one that minimises overhang; applied to both MANTA_RIBBON/ and
    MANTA_LIGHT/, average overhang is now ~1% (worst ~4%, small fillets).
    Every file is now pre-rotated -- import and print as-is.
    [01_SEG_00L.stl, 02_SEG_00R.stl, 03_SEG_01L.stl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]
2026-09-23 Fix manta_orient.py to prefer a solid bed-contact footprint, not just the lowest overhang number
    Minimising overhang alone picked orientations balanced on a tiny point for
    many parts -- great overhang %, terrible bed adhesion, a part that
    detaches mid-print. Now scores every candidate on both overhang AND
    footprint area (the mesh's own largest flat faces -- the actual cut faces
    -- are added as priority candidates too, not just a generic direction
    sweep), picking the largest footprint among near-optimal overhang
    candidates. Down from most parts balancing on <20mm2 to only 12-14 of 42
    still small (mostly the naturally tapered foot-tip segments and the thin
    pin) -- those are now explicitly flag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
    [01_SEG_00L.stl, 02_SEG_00R.stl, 03_SEG_01L.stl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]
2026-09-23 Update README with the honest post-fix overhang/footprint numbers
2026-09-23 Fix print-orientation: prioritize footprint over overhang minimization
    The previous overhang-first selection kept finding orientations balanced
    on a single point (part 14 down to 74mm2), great overhang% but no real
    bed adhesion. Flat-face detection was also using too loose a coplanarity
    threshold (~11deg) and blending real flat faces into curved relief,
    missing the lengthwise L/R seam face entirely -- often a segment's
    largest flat area.
    Tightened flat-face clustering to ~2.5deg and flipped the selection to
    footprint-first: among candidates with a solid >=400mm2 footprint and a
    tolerable overhang, pick lowest overhang, rather than the reverse. Result:
    all 42 parts (both competition and pers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
    [01_SEG_00L.stl, 02_SEG_00R.stl, 03_SEG_01L.stl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]
2026-09-23 Orient parts on their real joint cut faces, not just any flat face
    Real print testing on part 14 found a case where the chosen orientation
    had good footprint and overhang numbers but wasn't actually a joint
    face -- the conical tenon ended up pointing sideways, needing a support
    the numbers never showed.
    manta_orient.py now identifies a part's two real crosswise cut/joint
    faces (the flat-face cluster whose position sits at the part's actual
    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
    [03_SEG_01L.stl, 04_SEG_01R.stl, 05_SEG_02L.stl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]
2026-09-23 Fix cut-face matching: match by angle to exact tangent, not by position
    Part 14 still failed after the previous fix: on real-print testing, the
    tenon still stuck out to the side needing a support. Root cause -- the
    cut-face detector picked flat mesh clusters by which one sat at the most
    extreme position along the part's length, but a small fillet/chamfer near
    a tenon's base can be more "extreme" than the real cut face: on part 14 a
    ~1700mm2 fillet ring outscored the real ~12700mm2 socket face on position
    alone, so the part rested on the wrong surface entirely.
    Now matches flat clusters by ANGLE to the exact tangent(cuts[k]) /
    tangent(cuts[k+1]) directions the generator itself used to define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
    [07_SEG_03L.stl, 13_SEG_06L.stl, 14_SEG_06R.stl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]
2026-09-23 Fix infill floor bug in strength checks, add gate flag for backup-only checks
    The k = max(0.30, INFILL) floor in both strength checkers silently treated
    any infill below 30% as if it were 30% -- meaningless below that, and wrong.
    Harmless for the competition variant (always >=35% infill, above the
    floor), but for the personal variant at 20% infill it was reporting the
    "tenon+pin, no glue" backup margin as 1.4x when the honest, linear-with-
    infill value is 0.9x -- just under the design's own 1.0x bar.
    Floor reduced to a numerical-only guard (0.02) and chk() gained a `gate`
    param: the two PETG-only "no glue" backup checks in the personal variant
    are now marked gate=False, so they stay visible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
2026-09-28 Fix tenon/socket position at fork-zone joints — was breaching the outer wall
    Lucia caught this visually while printing MANTA_LIGHT part 39 (SEG_21R):
    the tenon cone sat right at the edge of the part instead of centered,
    "sticking out sideways" rather than being fully inside the material.
    Root cause: the crosswise tenon/socket Y-position (`cc`) was computed
    from the WHOLE segment's volumetric centroid (`ap.Center().y`). That's a
    fine proxy for a segment with a roughly constant cross-section along its
    length, but for a segment that tapers sharply (a forked foot/knee zone),
    the whole-body centroid can sit far from where the CUT FACE's own local
    cross-section actually is. Verified directly: a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
    [01_SEG_00L.stl, 02_SEG_00R.stl, 03_SEG_01L.stl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]
2026-09-28 Fix tenon/socket position properly: use the cut face's true 3D centroid
    The previous fix (a703c94/a90efc4) used a global-Y bounding-box offset to
    find the cut face's centre, which only handled the specific failure mode
    seen at the fork zones. Lucia caught a second, worse case while examining
    the parts: near the lumbar (a twisted zone, TWIST_S), the tenon centre
    computed that way landed entirely OUTSIDE the actual cross-section, in
    empty space, not just close to an edge — because a global-Y offset
    silently assumes "sideways" always means the global Y axis, which breaks
    down wherever the section has rotated away from its untwisted starting
    orientation.
    Fixed properly: the tenon/socket centr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
    [01_SEG_00L.stl, 02_SEG_00R.stl, 03_SEG_01L.stl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]
2026-09-28 Fix joint geometry (pegs poking out, crown part lost), crown fold, joint strength model
    Reported from real printing of MANTA_LIGHT: part 39 had a second "peg"
    sticking out of its side, the rear-leg parts had pegs out of their bottoms,
    and part 23 was only a cone.
    - Pegs were buried half their length (22 mm) inside their own part. On
    curved/tapering parts that buried half broke out through the side or
    bottom; on the tight crown it collided with the socket at the part's
    other end and the CAD boolean left only the cone. Pegs now keep a 3 mm
    root and protrude only into the neighbour's socket (socket 0.6 mm deeper
    so the glue faces meet, not the tip).
    - Every joint is volume-checked wh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
    [01_SEG_00L.stl, 02_SEG_00R.stl, 03_SEG_01L.stl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]
2026-09-28 Close every socket inside one part, 2 mm socket walls, engraved labels
    Reported from real printing: part 35 (SEG_19R) had an open half-hole on
    its seam face instead of a closed socket.
    - Where a whole piece meets a split L/R pair (cut 19) a single central peg
    straddled the seam, leaving an open half-socket in each half. The whole
    piece now carries two pegs, one centred in each half; every peg and
    socket is assigned to exactly one part.
    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
    [01_SEG_00L.stl, 02_SEG_00R.stl, 03_SEG_01L.stl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]
2026-09-28 Description + Board: say that cuts and pegs are computed, and how
    The joints are not slicer cuts with generic connectors: the script places
    cuts by length and curvature, >= 70 mm clear of the peak-bending knee and
    lumbar; each peg is centred on its own cut face, sized to the local section
    (which follows the bending moment) and shrunk to keep a 2 mm socket wall;
    pins only at the two most-loaded joints; every joint verified by virtual
    assembly. Description still 1 page, 492 words.
2026-09-29 Honest support numbers, least-support orientation, exact peg fit in the print STLs
    - "Prints without supports" was never measured and not true. manta_orient.py
    now picks, per part, the orientation with the least area a slicer would
    support (>50 deg overhang, off the bed) on a solid base: 23 of 42
    competition parts (26 of 42 light) need none, the rest a little from the
    build plate. Board / Description / README / PARTS_LIST say so, list the
    parts that need it, and advise "Support on build plate only" (never
    "Everywhere" -- it fills the peg sockets and pin holes).
    - Print STLs exported at 0.03 mm (was 0.45 mm): the coarse export ate the
    0.12 mm peg clearance (~0.05 mm left, some p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
    [01_SEG_00L.stl, 02_SEG_00R.stl, 03_SEG_01L.stl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]
2026-09-29 Pins through both pegs, pointed sockets, light variant retargeted to 70 kg
    - One pin line per lumbar joint through both pegs; holes from each side
    face stop 0.5 mm short of the seam; uniform D-profile pins print lying
    on a 0.6 mm flat.
    - Peg sockets end in a 45 deg point: no support inside, no blockers.
    - Light variant: 70 kg occupant, 15 % infill, 4 perimeters.
    - Joint check: pins stay inside the chair and never share a hole.
    - Print lists regenerated with per-part support tags (29/42 and 28/42
    parts need none).
    [01_SEG_00L.stl, 03_SEG_01L.stl, 04_SEG_01R.stl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]
2026-09-29 Holes shaped for how each part prints; supports checked in PrusaSlicer
    - manta_orient.py: fits the Prusa CORE One volume, centres each part,
    weighs support inside a socket 100x, writes ORIENT.json.
    - manta_teardrop.py: sockets lying sideways get a teardrop roof pointing
    up, ends facing up are pointed (>= 60 deg); pin holes have no blind end,
    they taper (the pin's stop) into a channel out through the seam.
    - manta_print_ready.py runs generator -> orient -> generator -> orient.
    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
    [01_SEG_00L.stl, 02_SEG_00R.stl, 03_SEG_01L.stl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]
2026-09-29 manta_verify.py: one command runs every check and prints PASS/FAIL
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2026-10-10 Fix the crossing: the ribbon no longer passes through itself
    After the crown the ribbon comes back down and crosses the backrest on
    its way to the rear legs. Cut into parts, the two bands shared volume
    (parts 27/29/30 up to 52 % of theirs) and no check noticed: the virtual
    assembly only compared neighbours along the ribbon.
    - manta_ribbon*.py step 3c: a part is trimmed wherever it would run into
    an earlier part of the ribbon (0.25 mm glue gap). The backrest stays
    whole; the loop's end is epoxied onto its front, the tail brace onto
    its back, as a saddle. Part 29 becomes two pieces (the new one is 43,
    after the pin: no other number moves). 37 of the print files are
    byte-for-byte wha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
2026-11-03 Built: photos of the full-size prototype, the story, real costs
    - Board: four photos of the printed and assembled chair (light variant)
    next to the render, with the first study model for scale; the parts
    key now shows part 43.
    - Description rewritten as a story: a wave that rose from the sea floor
    and stayed -- blue feet, foam-pale crest, white seams of thickened
    epoxy as sea foam, the seat's M for Manta and Mare. 492 words, 1 page.
    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
2026-11-03 Board step 5: name the crossing parts (27, 28, 43 front; 29, 30 back)
2026-11-03 Board: swap photos so every chair is shown whole
2026-11-03 Description: every part's meaning (fins, side M, crest, colour, foam), the self-checking engineering; Board caption
2026-11-03 Board as a section through the ocean: oxygen above, waste below; story in prose; 43 parts
    - Board: sunlit surface with rising oxygen bubbles above the waterline,
    the deep below with light text, a sea floor with plastic debris and a
    bar of what this chair wastes (supports 0.7 %); three pillars in the
    header (oxygen, waste, life); callouts on the render; depth-coloured
    bands, steps and biomimicry markers; key grid without its white frame.
    - Description: the story as prose (oxygen, plastic in the ocean, under
    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
2026-11-03 Plastic floats, life swims below: debris on the waterline, mantas in the deep; microplastics, recycled PETG, printing with sense
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2026-11-03 Description follows the jury's five criteria: idea, printing, assembly, strength and stability, open design; clear first sentence; 498 words in all
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2026-11-03 CC BY-SA 4.0 license; Board: the entry (120 kg) and the built chair (70 kg) named apart, one clear strength message, real signs (× Ø ° ²), short assembly steps; smooth exploded view
2026-11-03 One algorithm, presets for who the chair is for (the light chair runs manta_ribbon.py, not a copy); ocean zone colours everywhere; Board: how the form was found, true colour text, rounded images, tid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
2026-11-03 Board: the form found in three generations (v3 is MANTA), more air in the stability column and the biomimicry
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2026-11-03 Board: THE FORM as a turquoise column right of the render, mirroring THE IDEA; stability as a calm table with larger type
2026-11-03 Board: stability column spread over its full height with much larger type; larger biomimicry
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
